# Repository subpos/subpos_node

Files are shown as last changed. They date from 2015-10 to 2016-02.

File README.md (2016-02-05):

# SubPos Node Gerber Files and Firmware

The latest firmware should be used with the latest version of the ESP firmware, available here - https://github.com/subpos/esp_firmware_v2

You can order 3 of these boards for $7.5 including shipping from OSHPark here - https://oshpark.com/shared_projects/0TVEe4yb

Note, the current Node design will not support Time of Flight. Because of this, there is no need to populate QG1 as the firmware just uses the internal PIC oscillator.

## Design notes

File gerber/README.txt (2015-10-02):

Gerber File	Extension
Bottom Copper	GBL
Bottom Silkscreen	GBO
Bottom Soldermask	GBS
Top Copper	GTL
Top Silkscreen	GTO
Top Soldermask	GTS
Drill File	TXT
Drill Station Info File	dri
Photoplotter Info File	gpi
Mill Layer	GML
Top Paste	GTP

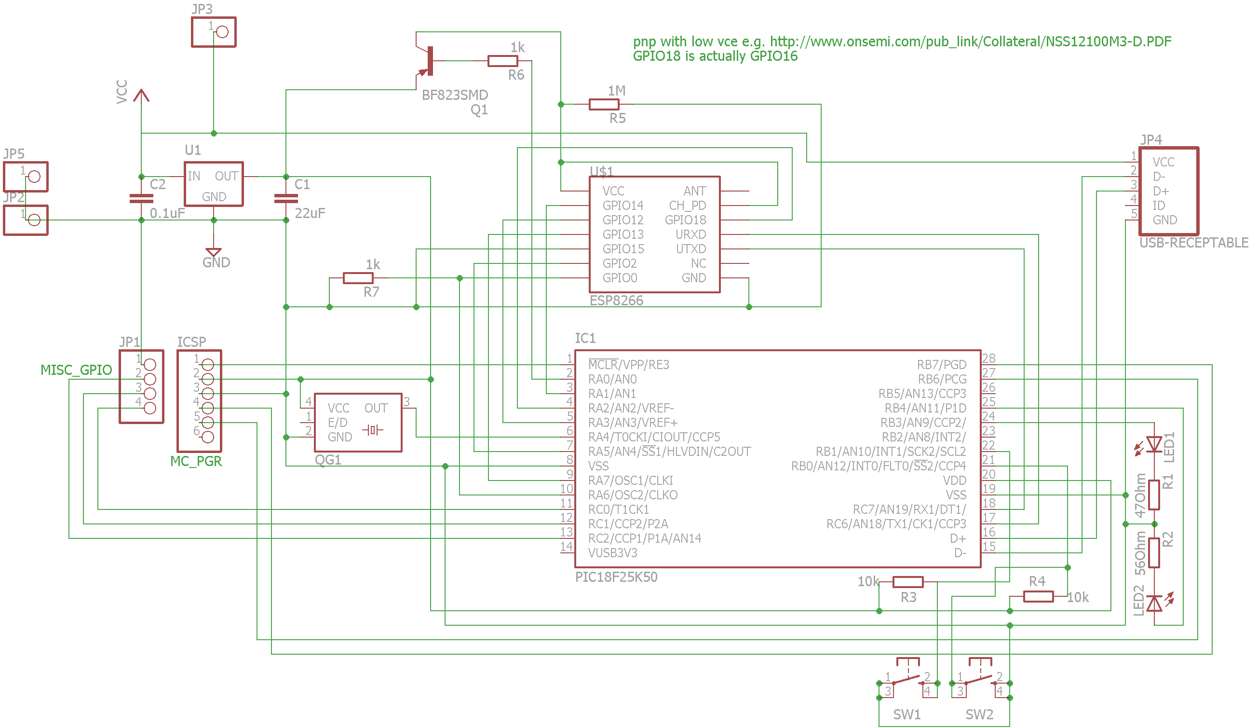
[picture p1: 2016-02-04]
Schematic.png

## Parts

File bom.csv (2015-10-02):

Part | Value | Device | Package | Description
C1 | 22µF Tantalum 4V | C-EUC0805 | C0805 | CAPACITOR, European symbol
C2 | 0.1µF Ceramic 25V | C-EUC0805 | C0805 | CAPACITOR, European symbol
IC1 | PIC18F25K50 | PIC18F25K50-I/SO | SO28W | PIC18F25K50 28 pin DIP
ICSP | 2.54mm | PINHD-1X6 | 1X06 | PIN HEADER
JP1 | 2.54mm | PINHD-1X4 | 1X04 | PIN HEADER
JP2 |  | FCI-10103594-0001LF | USB-RECEPTABLE | USB Receptable
LED1 | RED 22MCD | KPT-2012LSURCK | CHIPLED_0805 | LED
LED2 | GREEN 3MCD | KPT-2012LCGCK | CHIPLED_0805 | LED
Q1 | PNP Low Vce | NSV40200LT1G | SOT23-BEC | PNP Transistror
R1 | 47Ohm | R-EU_M0805 | M0805 | RESISTOR, European symbol
R2 | 56Ohm | R-EU_M0805 | M0805 | RESISTOR, European symbol
R3 | 10k | R-EU_M0805 | M0805 | RESISTOR, European symbol
R4 | 10k | R-EU_M0805 | M0805 | RESISTOR, European symbol
R5 | 1M | R-EU_M0805 | M0805 | RESISTOR, European symbol
R6 | 1k | R-EU_M0805 | M0805 | RESISTOR, European symbol
R7 | 1k | R-EU_M0805 | M0805 | RESISTOR, European symbol
SW1 | SPST_TACT-KMR2 | SPST_TACT-KMR2 | KMR2 | SMT 6mm switch, EVQQ2 series
SW2 | SPST_TACT-KMR2 | SPST_TACT-KMR2 | KMR2 | SMT 6mm switch, EVQQ2 series
U1 | MIC5209-X.XYS | MIC5209-3.3YS | SOT223 | LDO REGULATOR
U2 | ESP8266 | ESP8266 | ESP-03 | ESP8266 Wifi module 03 & 04

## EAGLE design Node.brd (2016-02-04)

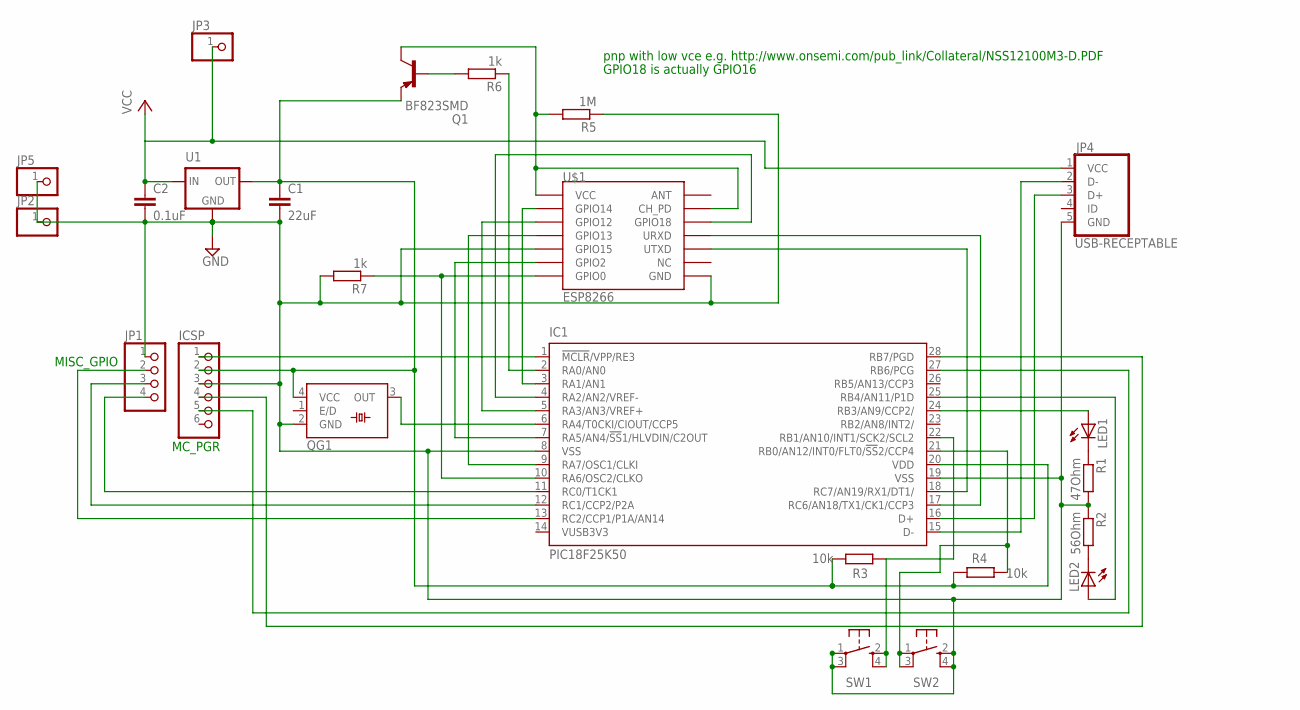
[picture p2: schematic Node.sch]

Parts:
C1: 22uF; C0805
C2: 0.1uF; C0805
IC1: PIC18F25K50; SO28W
ICSP: PINHD-1X6; 1X06
JP1: PINHD-1X4; 1X04
JP2, JP3, JP5: PINHD-1X1; 1X01
JP4: USB-RECEPTABLE; FCI-10103594-0001LF
LED1, LED2: LEDCHIPLED_0805; CHIPLED_0805
Q1: BF823SMD; SOT23-BEC
QG1: SM77H
R1: 47Ohm; M0805
R2: 56Ohm; M0805
R3, R4: 10k; M0805
R5: 1M; M0805
R6, R7: 1k; M0805
SW1, SW2: SPST_TACT-KMR2; KMR2
U1: MIC5209-X.XYS; SOT223
U$1: ESP8266; ESP-03

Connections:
GND: C1.2, C2.2, IC1.8 (VSS), IC1.19 (VSS), ICSP.3, JP1.1, JP2.1, JP4.5 (GND), JP5.1, QG1.2 (GND), R1.2, R2.1, R5.1, R7.2, SW1.1, SW1.3 (P1), SW2.2 (S), SW2.4 (S1), U1.2 (GND), U1.4 (GND), U$1.GND, U$1.GPIO15
unnamed: IC1.28 (RB7/PGD), ICSP.4
unnamed: C1.1, IC1.20 (VDD), ICSP.2, Q1.E, QG1.4 (VCC), R3.1, R4.2, U1.3 (OUT)
unnamed: IC1.27 (RB6/PCG), ICSP.5
unnamed: IC1.2 (RA0/AN0), R6.1
unnamed: IC1.17 (RC6/AN18/TX1/CK1/CCP3), U$1.URXD
unnamed: IC1.18 (RC7/AN19/RX1/DT1/), U$1.UTXD
unnamed: IC1.1 (!MCLR!/VPP/RE3), ICSP.1
unnamed: IC1.3 (RA1/AN1), U$1.GPIO14
unnamed: IC1.5 (RA3/AN3/VREF+), U$1.GPIO12
unnamed: IC1.16 (D+), JP4.3 (D+)
unnamed: IC1.15 (D-), JP4.2 (D-)
unnamed: LED1.C, R1.1
unnamed: IC1.24 (RB3/AN9/CCP2/), LED1.A
unnamed: LED2.C, R2.2
unnamed: IC1.25 (RB4/AN11/P1D), LED2.A
unnamed: IC1.11 (RC0/T1CK1), JP1.4
unnamed: IC1.13 (RC2/CCP1/P1A/AN14), JP1.2
unnamed: IC1.9 (RA7/OSC1/CLKI), U$1.GPIO13
unnamed: IC1.6 (RA4/T0CKI/CIOUT/CCP5), QG1.3 (OUT)
unnamed: IC1.12 (RC1/CCP2/P2A), JP1.3
unnamed: IC1.7 (RA5/AN4/!SS!1/HLVDIN/C2OUT), U$1.GPIO2
unnamed: IC1.4 (RA2/AN2/VREF-), U$1.GPIO18
unnamed: IC1.10 (RA6/OSC2/CLKO), R7.1, U$1.GPIO0
unnamed: IC1.22 (RB1/AN10/INT1/SCK2/SCL2), R3.2, SW1.2 (S), SW1.4 (S1)
unnamed: IC1.21 (RB0/AN12/INT0/FLT0/!SS!2/CCP4), R4.1, SW2.1, SW2.3 (P1)
unnamed: Q1.B, R6.2
unnamed: Q1.C, R5.2, U$1.CH_PD, U$1.VCC
VCC: C2.1, JP3.1, JP4.1 (VCC), U1.1 (IN)

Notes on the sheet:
MC_PGR
MISC_GPIO
GPIO18 is actually GPIO16
pnp with low vce e.g. http://www.onsemi.com/pub_link/Collateral/NSS12100M3-D.PDF

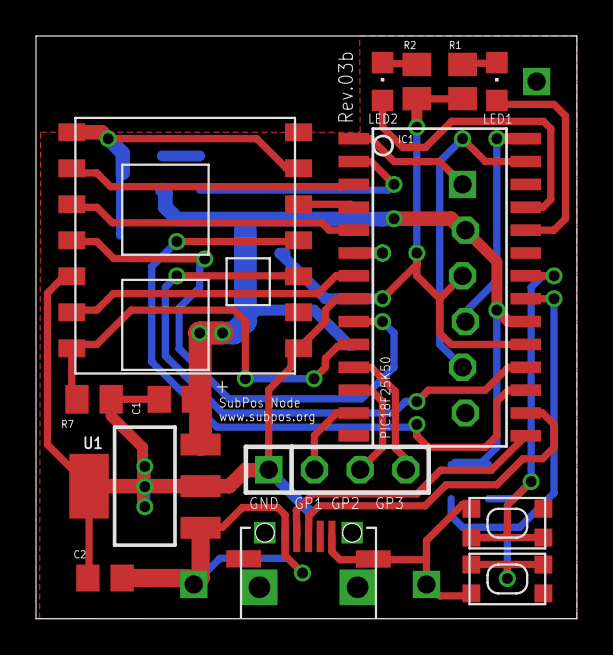
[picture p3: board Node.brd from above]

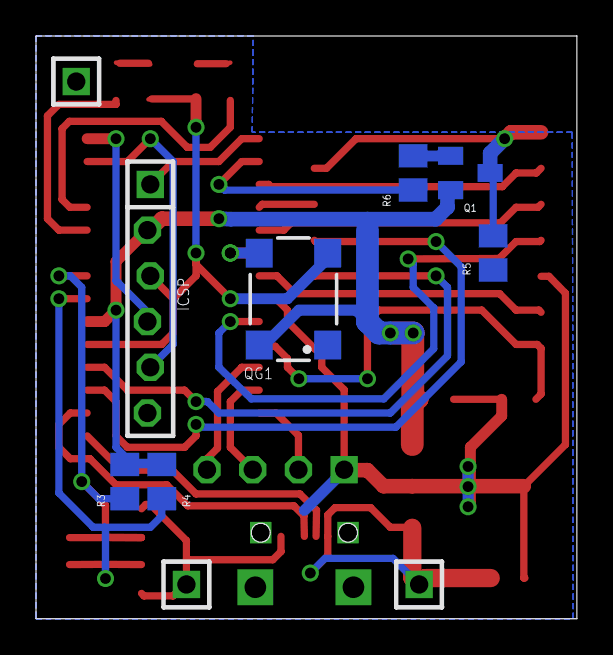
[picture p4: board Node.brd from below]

Board: 2 copper layers, 30.0 x 32.4 mm, 24 parts (9 on the bottom side), 29 nets.

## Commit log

2015-09-19 SubPos Node Rev 03a PCB files initial commit.
    [bom.csv]
2015-09-19 Added USB Driver
2015-09-19 Firmware now works when plugged into USB power only.
2015-10-02 Added R5 to GPIO0 to pulldown. Fixed USB connector pads to add structural integrity.
    [bom.csv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]
2015-10-22 Fix issue when connecting to USB power supply.
2016-02-04 Added Eagle sources and Schematic.png
    [Node.brd, Node.sch]

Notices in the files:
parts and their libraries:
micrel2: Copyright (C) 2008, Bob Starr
